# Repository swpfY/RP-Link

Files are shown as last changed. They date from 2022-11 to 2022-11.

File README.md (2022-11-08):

## RP-Link

基于 [Picoprobe](https://github.com/raspberrypi/picoprobe) 的 [树莓派Pico](https://www.raspberrypi.com/documentation/microcontrollers/raspberry-pi-pico.html) 调试器。

- 原理图在：[RP-Link.pdf](./RP-Link.pdf)

- 实物图在： [static/RP-Link_.jpeg](./static/RP-Link_.jpeg)

- bom表在：[bom/ibom.html](./bom/ibom.html)
- genber文件在：[genber/](./genber/)

- 引脚定义如下图：

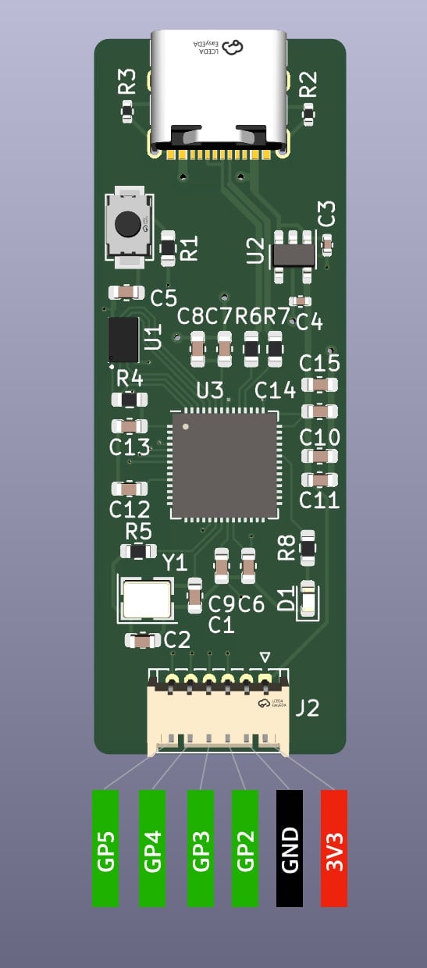
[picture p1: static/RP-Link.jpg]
RP-Link


> PCB设计参考自：[raspberry pi pico](https://www.raspberrypi.com/documentation/microcontrollers/) 和 [EnvOpenPico](https://github.com/Envious-Data/EnvOpenPico)

## 更多

[使用 CLion 调试树莓派 Pico](./doc/使用CLion调试树莓派Pico.md)

生成交互式Bom表单的插件为：[InteractiveHtmlBom](https://github.com/openscopeproject/InteractiveHtmlBom)

picoprobe 可执行文件可以在 [Releases](https://github.com/swpfY/RP-Link/releases) 中找到

> 🤪目前刚入门水平有限，还在学习，后续会继续优化迭代

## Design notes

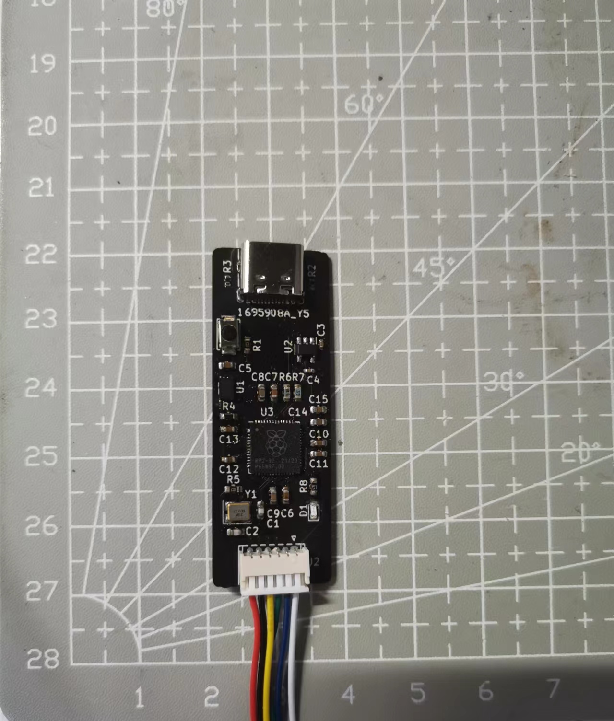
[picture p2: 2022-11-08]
static/RP-Link_.jpeg

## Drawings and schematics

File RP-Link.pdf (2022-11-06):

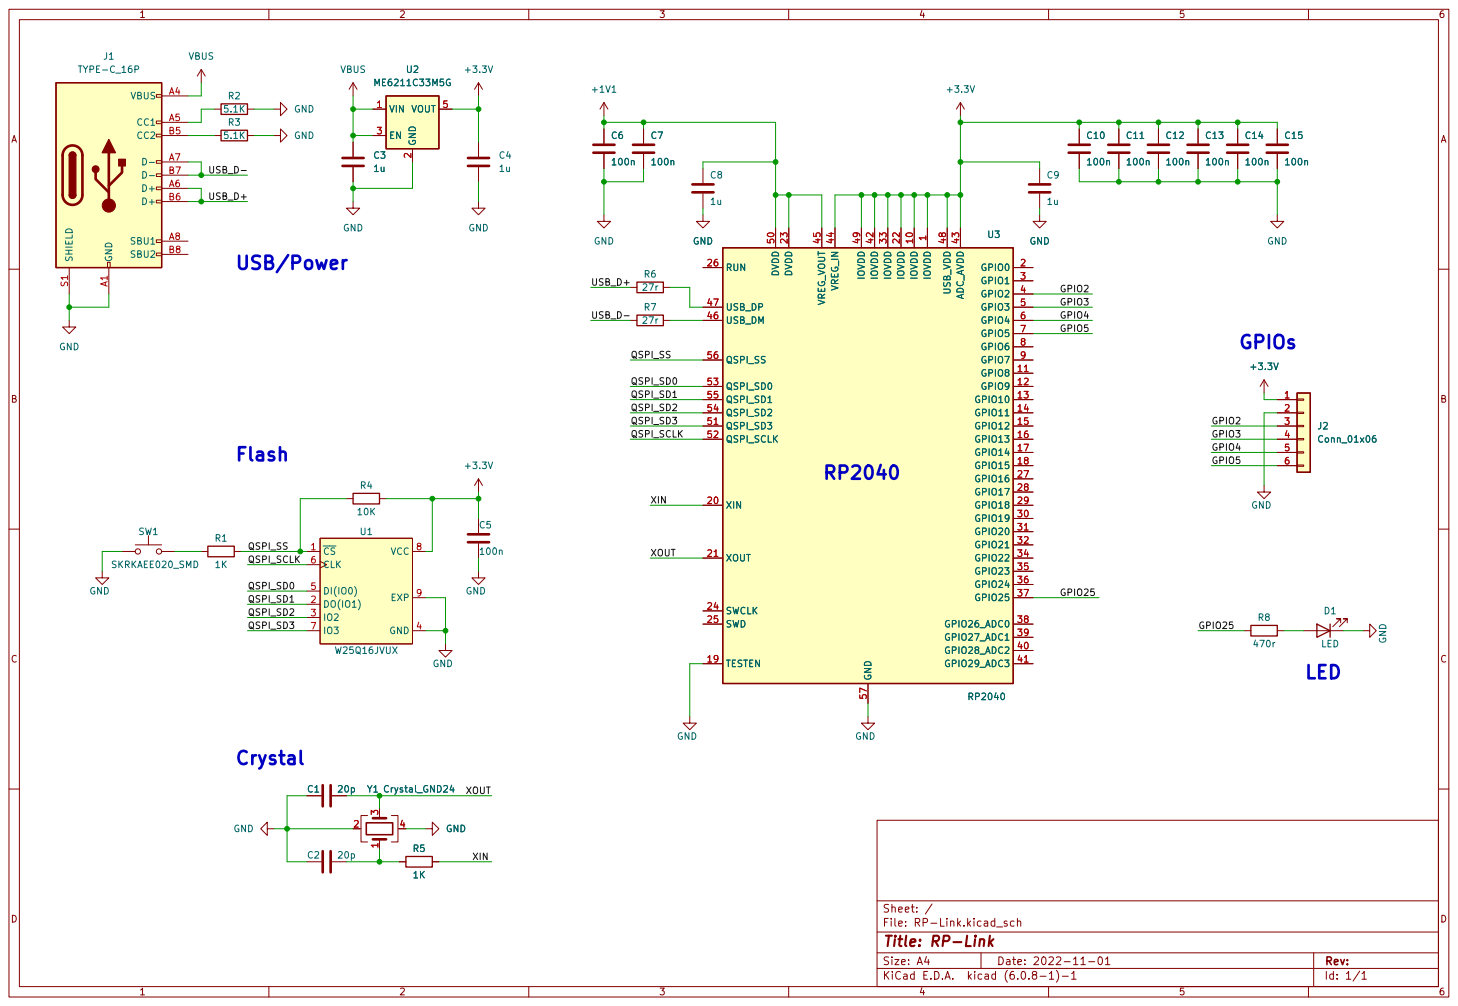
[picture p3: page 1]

1 IOVDD 10 GPIO8 11 GPIO9 12 GPIO10 13 GPIO11 14 GPIO12 15 GPIO13 16 GPIO14 17 GPIO15 18 TESTEN 19 GPIO0 2 XIN 20 XOUT 21 IOVDD 22 DVDD 23 SWCLK 24 SWD 25 RUN 26 GPIO16 27 GPIO17 28 GPIO18 29 GPIO1 3 GPIO19 30 GPIO20 31 GPIO21 32 IOVDD 33 GPIO22 34 GPIO23 35 GPIO24 36 GPIO25 37 GPIO26_ADC0 38 GPIO27_ADC1 39 GPIO2 4 GPIO28_ADC2 40 GPIO29_ADC3 41 IOVDD 42 ADC_AVDD 43 VREG_IN 44 VREG_VOUT 45 USB_DM 46 USB_DP 47 USB_VDD 48 IOVDD 49 GPIO3 5 DVDD 50 QSPI_SD3 51 QSPI_SCLK 52 QSPI_SD0 53 QSPI_SD2 54 QSPI_SD1 55 QSPI_SS 56 GND 57 GPIO4 6 GPIO5 7 GPIO6 8 GPIO7 9 U3 RP2040 GND

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

Id: 1/1 Title: RP-Link

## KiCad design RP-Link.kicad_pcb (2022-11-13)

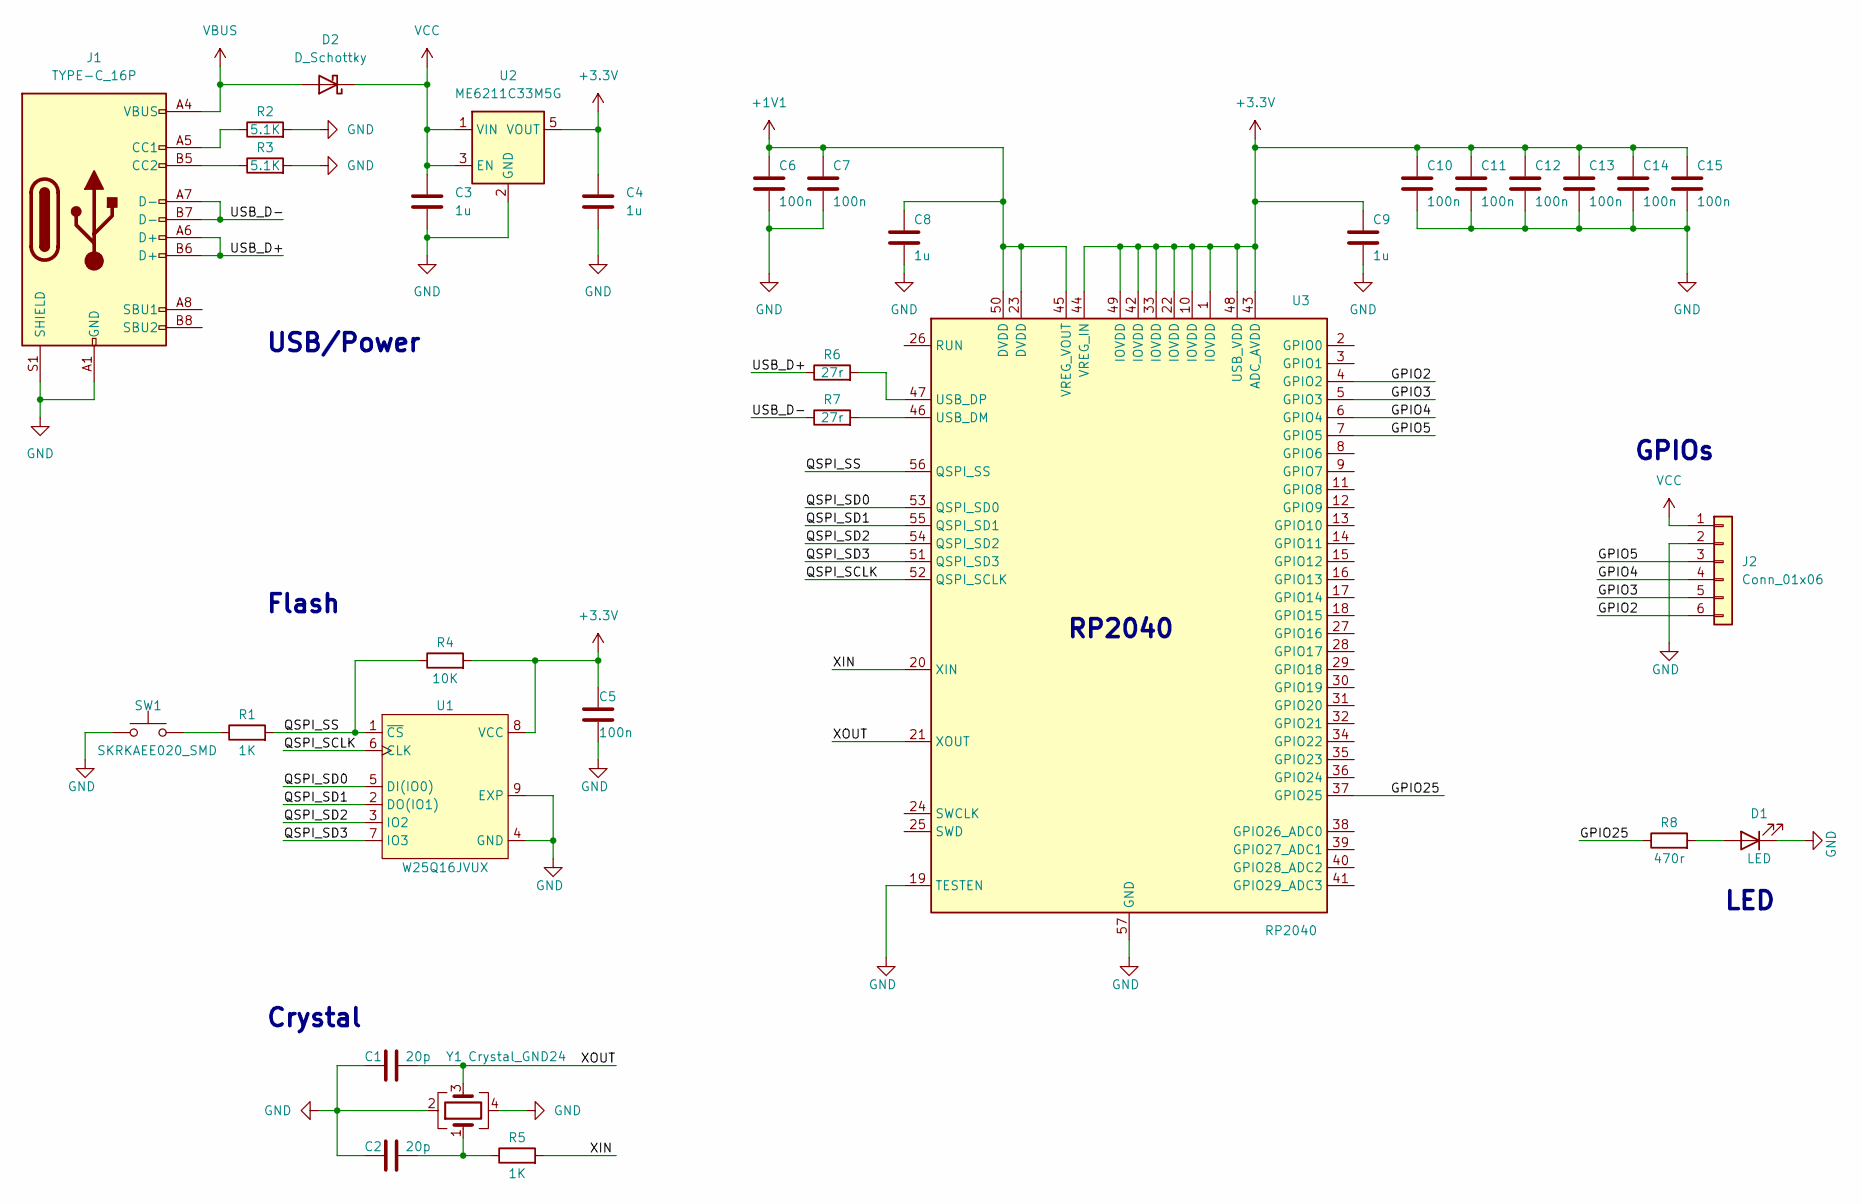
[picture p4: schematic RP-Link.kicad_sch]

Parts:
C1, C2: 20p; C_0402_1005Metric
C3, C4: 1u; C_0603_1608Metric
C5, C6, C7, C10, C11, C12, C13, C14, C15: 100n; C_0402_1005Metric
C8, C9: 1u; C_0402_1005Metric
D1: LED; LED_0603_1608Metric
D2: D_Schottky; D_SOD-123F
J1: TYPE-C_16P; USB_C_Receptacle_XKB_U262-16XN-4BVC11
J2: Conn_01x06; Hirose_DF13-06P-1.25DS_1x06_P1.25mm_Horizontal
R1, R5: 1K; R_0402_1005Metric
R2, R3: 5.1K; R_0402_1005Metric
R4: 10K; R_0402_1005Metric
R6, R7: 27r; R_0402_1005Metric
R8: 470r; R_0402_1005Metric
SW1: SKRKAEE020_SMD; SKRKAEE020
U1: W25Q16JVUX; USON-8_2x3mm_P0.6mm
U2: ME6211C33M5G; SOT-23-5
U3: RP2040; QFN-56-1EP_7x7mm_P0.4mm_EP3.2x3.2mm
Y1: Crystal_GND24; Crystal_SMD_3225-4Pin_3.2x2.5mm

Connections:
+1V1: C6.1, C7.1, C8.1, U3.23 (DVDD), U3.45 (VREG_VOUT), U3.50 (DVDD)
+3.3V: C4.1, C5.1, C9.1, C10.1, C11.1, C12.1, C13.1, C14.1, C15.1, R4.2, U1.8 (VCC), U2.5 (VOUT), U3.1 (IOVDD), U3.10 (IOVDD), U3.22 (IOVDD), U3.33 (IOVDD), U3.42 (IOVDD), U3.43 (ADC_AVDD), U3.44 (VREG_IN), U3.48 (USB_VDD), U3.49 (IOVDD)
/GPIO2: J2.6, U3.4 (GPIO2)
/GPIO3: J2.5, U3.5 (GPIO3)
/GPIO4: J2.4, U3.6 (GPIO4)
/GPIO5: J2.3, U3.7 (GPIO5)
/GPIO25: R8.1, U3.37 (GPIO25)
/QSPI_SCLK: U1.6 (CLK), U3.52 (QSPI_SCLK)
/QSPI_SD0: U1.5 (DI(IO0)), U3.53 (QSPI_SD0)
/QSPI_SD1: U1.2 (DO(IO1)), U3.55 (QSPI_SD1)
/QSPI_SD2: U1.3 (IO2), U3.54 (QSPI_SD2)
/QSPI_SD3: U1.7 (IO3), U3.51 (QSPI_SD3)
/QSPI_SS: R1.2, R4.1, U1.1 (~CS), U3.56 (QSPI_SS)
/USB_D+: J1.A6 (D+), J1.B6 (D+), R6.1
/USB_D-: J1.A7 (D-), J1.B7 (D-), R7.1
/XIN: R5.2, U3.20 (XIN)
/XOUT: C1.2, U3.21 (XOUT), Y1.3
GND: C1.1, C2.1, C3.2, C4.2, C5.2, C6.2, C7.2, C8.2, C9.2, C10.2, C11.2, C12.2, C13.2, C14.2, C15.2, D1.1 (K), J1.A1 (GND), J1.A12 (GND), J1.B1 (GND), J1.B12 (GND), J1.S1 (SHIELD), J2.2, R2.2, R3.2, SW1.1, U1.4 (GND), U1.9 (EXP), U2.2 (GND), U3.19 (TESTEN), U3.57 (GND), Y1.2, Y1.4
unnamed: C2.2, R5.1, Y1.1
unnamed: D1.2 (A), R8.2
unnamed: J1.A5 (CC1), R2.1
unnamed: J1.B5 (CC2), R3.1
unnamed: R1.1, SW1.2
unnamed: R6.2, U3.47 (USB_DP)
unnamed: R7.2, U3.46 (USB_DM)
VBUS: D2.2 (A), J1.A4 (VBUS), J1.A9 (VBUS), J1.B4 (VBUS), J1.B9 (VBUS)
VCC: C3.1, D2.1 (K), J2.1, U2.1 (VIN), U2.3 (EN)

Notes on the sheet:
RP2040
Crystal
Flash
USB/Power
LED
GPIOs

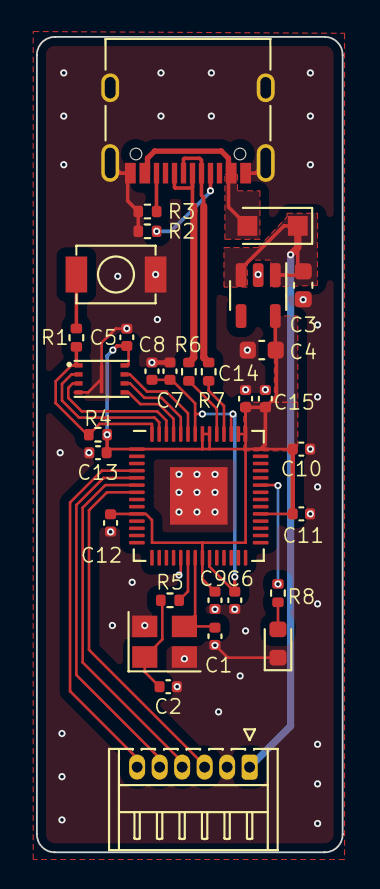
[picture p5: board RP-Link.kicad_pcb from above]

Board: 2 copper layers, 17.0 x 45.3 mm, 32 parts (0 on the bottom side), 27 nets.

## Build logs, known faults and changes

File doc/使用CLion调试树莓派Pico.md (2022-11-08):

## 使用 CLion 调试树莓派Pico

> 使用树莓派（如Raspberry Pi 4B）直接调试 Pico 是可行的，因为树莓派有 SWD 接口。对于本地开发来说可以使用官方提供的 [Picoprobe](https://github.com/raspberrypi/picoprobe) 项目结合 CLion 实现嵌入式代码调试。

### 环境配置

官方文档在 [Appendix A: Using Picoprobe](https://datasheets.raspberrypi.com/pico/getting-started-with-pico.pdf) 一节详细讲述了 `Picoprobe` 的操作步骤。其中连线为：

截屏2022-10-18 11.06.03

> UART连线可以不连接，并不影响调试，只是可以用来转发UART消息到本机

### 配置 CLion 调试

> 电脑系统为 macOS

打开「编辑配置」> 添加一个「嵌入式GDB服务器」

+ GDB 默认`Bundled GDB`
+ target remote ：`tcp:localhost:3333`
+ GDB 服务器选择上一节配置过的 `src/openocd` 的路径
+ GDB 参数为：`-f interface/picoprobe.cfg -f target/rp2040.cfg -s tcl`
+ 注意需要添加工作目录，不然无法找到`picoprobe.cfg`和`rp2040.cfg`，路径为上一节`openocd`的安装路径

截屏2022-10-18 11.11.48

还有就是「外设」中加载`.svd`文件路径为`$PICO_SDK_PATH/src/rp2040/hardware_regs/rp2040.svd`

### 参考

[Want to Flash and Debug an MCU Over the Air? Just Use Your Raspberry Pi](https://blog.jetbrains.com/clion/2021/03/flash-debug-over-air)

[使用picoprobe调试树莓派PICO（附调试包）](https://zhuanlan.zhihu.com/p/524649549)

[RaspberryPi Pico Dev Board](https://timsavage.github.io/rpi-pico-devboard/)

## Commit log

2022-11-08 update .gitignore
    - 保留genber目录
    - 删除fp-info-cache（缓存文件）
    [RP-Link-B_Cu.gbr, RP-Link-B_Mask.gbr, RP-Link-B_Paste.gbr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]
2022-11-08 update readme
    更新文档
2022-11-08 Update README.md
    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
2022-11-08 Update README.md
    更新readme
2022-11-13 修复一些问题
    #2
    [RP-Link-B_Cu.gbr, RP-Link-B_Mask.gbr, RP-Link-B_Paste.gbr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]
